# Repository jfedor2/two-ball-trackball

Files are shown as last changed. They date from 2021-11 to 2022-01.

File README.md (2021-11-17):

# DIY two-ball trackball

This repository contains design files and code that can be used to make a fully programmable two-ball, three-button USB trackball that looks like this:

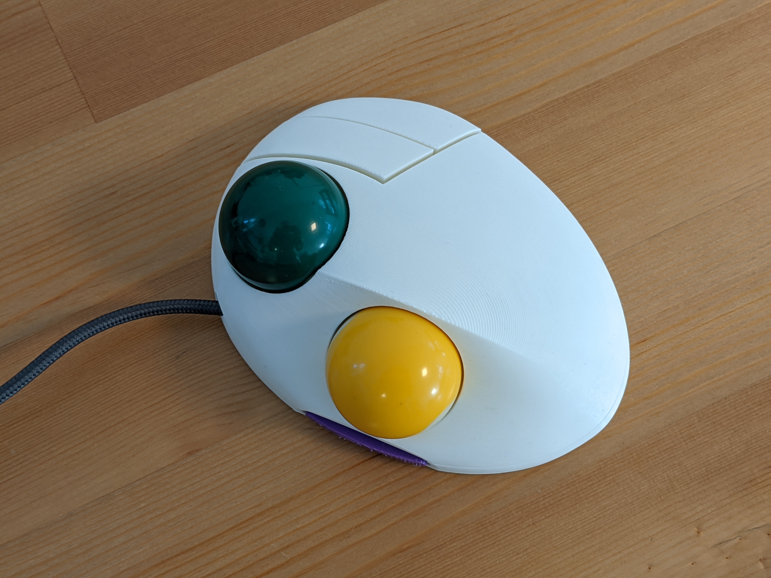
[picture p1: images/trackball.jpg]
Trackball photo


It uses the following components:

* two 38mm billiard balls
* two PMW3360 optical sensors
* [main PCB](https://github.com/jfedor2/rp2040-pmw3360)
* [second sensor PCB](https://github.com/jfedor2/pmw3360-breakout)
* [button switch mount PCBs](https://github.com/jfedor2/mouse-switch-mount-pcb)
* [3D printed case](3d-models)
* Omron D2FC switches (or any switches with the same footprint)
* 2.5mm zirconium oxide (or silicon nitride) bearing balls
* M3x4 screws for mounting the main PCB
* M2x4 screws for mounting the buttons and the secondary PCBs
* 3x10mm wood screws for assembling the case
* USB cable (cut off the device end and solder the wires directly to the PCB)

The main PCB uses the RP2040 chip from Raspberry Pi. The firmware supports remapping of ball and button functions using a configuration tool without the need to recompile the source code. All the configuration is stored on device, so the configuration tool is only needed to change the settings, not during normal use.

Each ball can be configured to control the cursor or to scroll, with independent CPI setting. High resolution scroll is supported (at least on Windows).

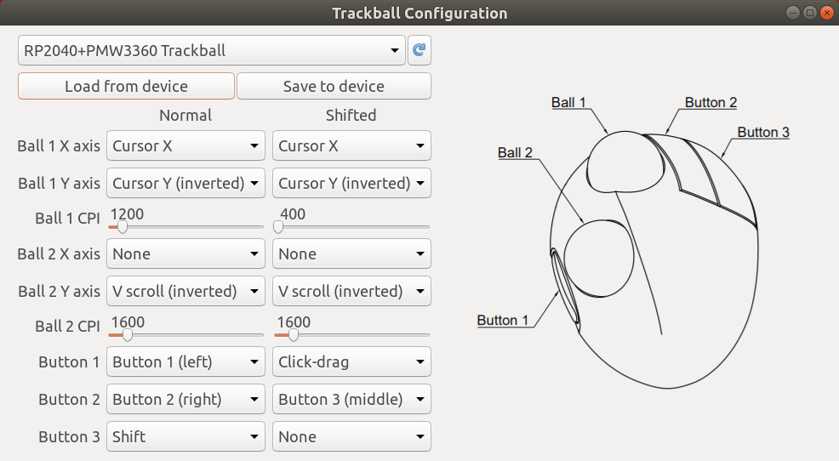
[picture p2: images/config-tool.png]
Configuration tool UI screenshot


So far I only tested the configuration tool on Linux, but it should in theory run on Windows and Mac as well. I will try to provide ready-to-use packages in the future.

The provided [UF2 file](firmware/trackball.uf2) can be used to flash the firmware onto the device. When first connected, a "RPI-RP2" drive will show up and you flash the chip by copying the UF2 file to that drive. If you want to flash it again, hold the BOOT button and press the RESET button on the board.

I printed the case parts with 0.2mm layer height and no supports, though you might want to enable supports for the top part if you're having trouble printing it without them.

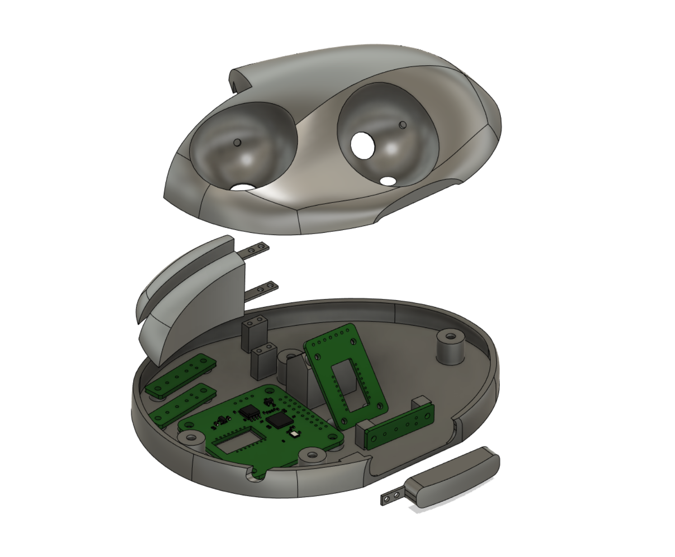
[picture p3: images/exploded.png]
Exploded view


The pin numbers are defined at the top of [trackball.cc](firmware/src/trackball.cc).

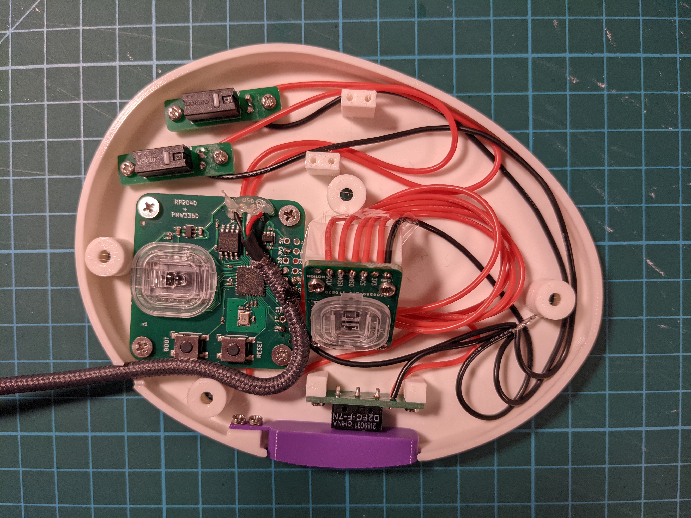
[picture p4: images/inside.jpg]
Insides of the case


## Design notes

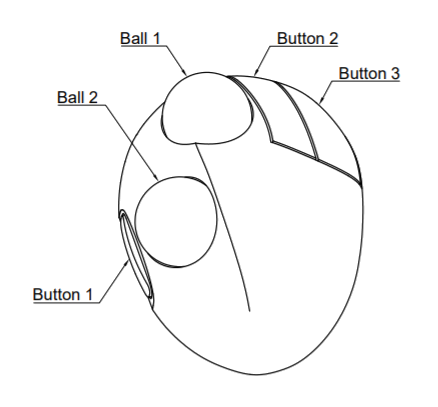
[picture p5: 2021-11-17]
config-tool/trackball.png

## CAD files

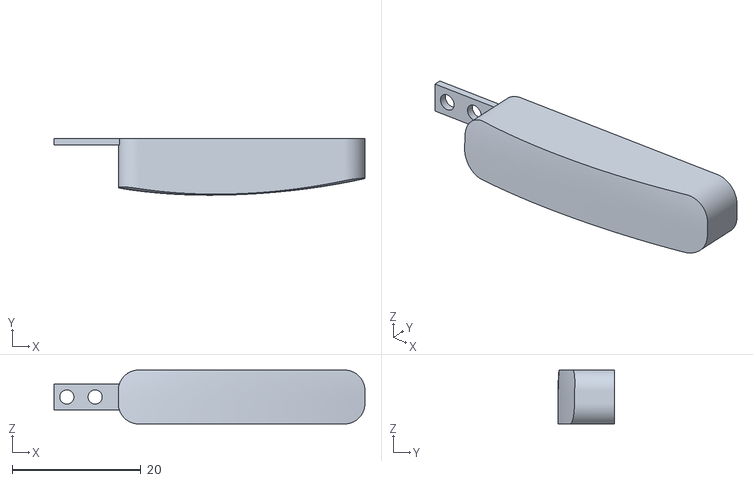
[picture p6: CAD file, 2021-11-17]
3d-models/Trackball12-Button3.stl
48.4 x 8.80 x 8.40

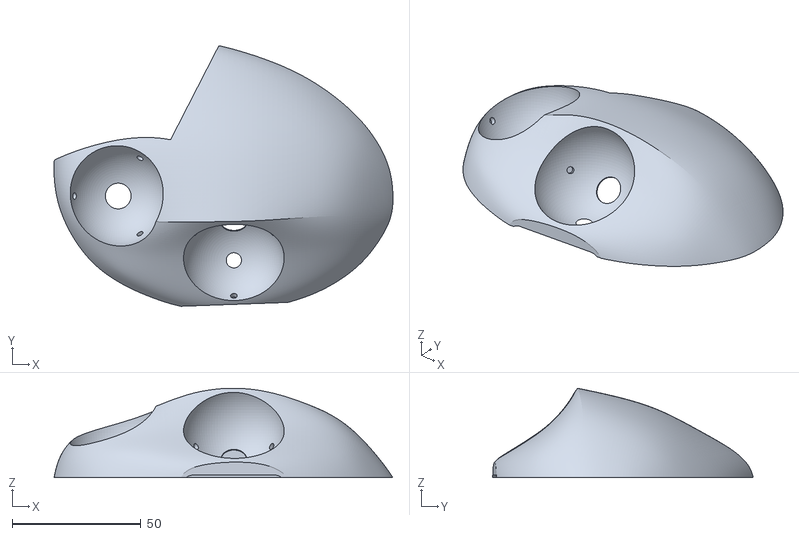
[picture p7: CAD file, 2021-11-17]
3d-models/Trackball12-Case-top.stl
131.9 x 101.4 x 34.8

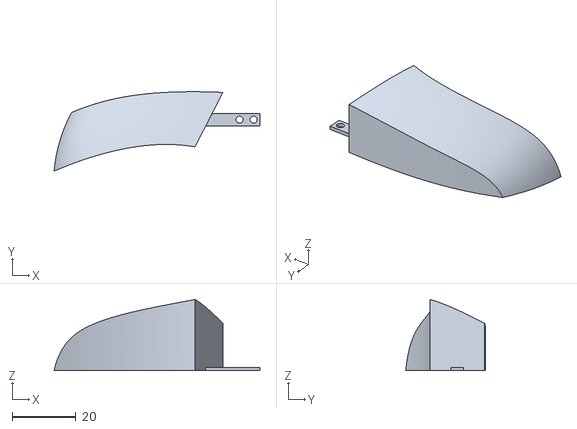
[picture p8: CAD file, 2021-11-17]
3d-models/Trackball12-Button1.stl
64.5 x 24.9 x 22.3

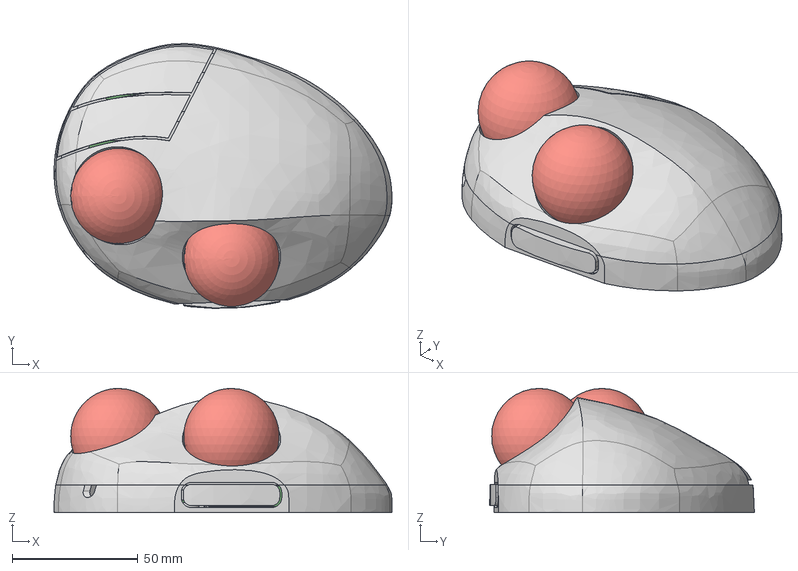
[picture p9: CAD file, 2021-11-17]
3d-models/Trackball12.step
134.5 x 105.4 x 49.4 mm

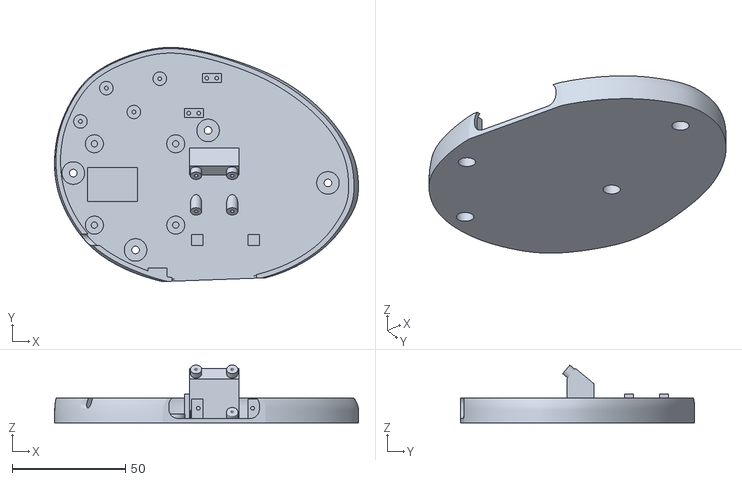
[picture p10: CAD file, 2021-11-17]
3d-models/Trackball12-Case-bottom.stl
134.5 x 103.6 x 25.6

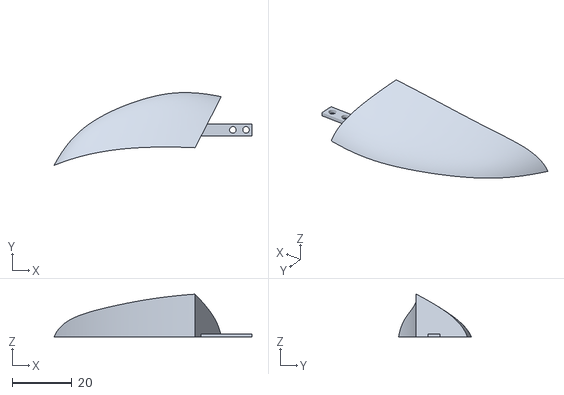
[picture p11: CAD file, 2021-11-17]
3d-models/Trackball12-Button2.stl
66.3 x 24.4 x 14.3

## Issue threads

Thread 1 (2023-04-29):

map the unused rp2040 pcb pins to buttons.

itsnoteasy, 2023-04-29:
I have built this project in a different case. however, there's not many buttons no back/ forward and you have to choose between middle click and layer shift. I'd appreciate it if you could map at least one extra button to the gpio, they're unused anyway. 2 to 3 buttons would be great. I like the layer shift because it prevents back/forward from being hit by accident.

I have tried to compile the code, but couldn't get the build environment setup. sorry for hassling you.

Closed 2023-04-30.

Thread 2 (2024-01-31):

SENSOR0 / BALL 1 stuck in perpetual diagonal movement

flacks, 2024-01-31:
SENSOR0 / BALL 1 seems to be stuck in perpetual diagonal movement. If I set the X axis to Cursor X and Y axis to Cursor Y (inverted), cursor perpetually moves down and to the right, diagonally. Accordingly, if I set Y axis to Cursor Y (not inverted), cursor perpetually moves up and to the right, diagonally. Any idea on how to debug this? Could it be a faulty PMW3360 sensor?

flacks, 2024-01-31:
I tried using the provided trackball.uf2 as well as building the firmware with the last Pico SDK, to the same result.

flacks, 2024-02-12:
Resolved - bad sensor. Thank you kindly, @jfedor2, for your help offline!

Closed 2024-02-12.

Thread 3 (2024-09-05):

Detailed wiring guide

tangbonze, 2024-09-05:
Your design is really fascinating. I want to make one myself.
In terms of wiring, I'm a little unclear how the second sensor and the switch connect to the pins of the main pcb.
Can you provide a clear wiring diagram?
Thanks a lot.

tangbonze, 2024-09-06:
Thanks a lot!

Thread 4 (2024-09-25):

Source for PWM3360 sensor and lense

PumaFPV, 2024-09-25:
Hey, where do you source your PWM3360 sensor and lenses please?
Thanks

jfedor2, 2024-09-25:
AliExpress.

PumaFPV, 2024-10-16:
Thanks for the answer. I hoped there was a better source :/

Closed 2024-10-16.

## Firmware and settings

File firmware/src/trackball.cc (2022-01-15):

/* 
 * The MIT License (MIT)
 *
 * Copyright (c) 2021 Jacek Fedorynski
 * Copyright (c) 2019 Ha Thach (tinyusb.org)
 *
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
 */

#include <stdio.h>
#include <stdlib.h>
#include <string.h>

#include <bsp/board.h>
#include <tusb.h>

#include <pico/bootrom.h>
#include <pico/stdlib.h>

#include <hardware/flash.h>
#include <hardware/gpio.h>

#include "crc.h"
#include "pmw3360.h"

// These IDs are bogus. If you want to distribute any hardware using this,
// you will have to get real ones.
#define USB_VID 0xCAFE
#define USB_PID 0xBACA

#define CONFIG_VERSION 1
#define CONFIG_SIZE 24

#define NBALLS 2
#define NBUTTONS 3

#define PRESUMED_FLASH_SIZE 2097152
#define CONFIG_OFFSET_IN_FLASH (PRESUMED_FLASH_SIZE - FLASH_SECTOR_SIZE)
#define FLASH_CONFIG_IN_MEMORY (((uint8_t*) XIP_BASE) + CONFIG_OFFSET_IN_FLASH)

uint button_pins[NBUTTONS] = { 16, 24, 26 };

#define SENSOR0_SPI spi0
#define SENSOR0_MISO 4
#define SENSOR0_MOSI 3
#define SENSOR0_SCK 2
#define SENSOR0_NCS 9
#define SENSOR1_SPI spi0
#define SENSOR1_MISO 20
#define SENSOR1_MOSI 23
#define SENSOR1_SCK 18
#define SENSOR1_NCS 25

PMW3360 sensors[NBALLS] = {
    PMW3360(SENSOR0_SPI, SENSOR0_MISO, SENSOR0_MOSI, SENSOR0_SCK, SENSOR0_NCS),
    PMW3360(SENSOR1_SPI, SENSOR1_MISO, SENSOR1_MOSI, SENSOR1_SCK, SENSOR1_NCS),
};

tusb_desc_device_t const desc_device = {
    .bLength = sizeof(tusb_desc_device_t),
    .bDescriptorType = TUSB_DESC_DEVICE,
    .bcdUSB = 0x0200,
    .bDeviceClass = 0x00,
    .bDeviceSubClass = 0x00,
    .bDeviceProtocol = 0x00,
    .bMaxPacketSize0 = CFG_TUD_ENDPOINT0_SIZE,

    .idVendor = USB_VID,
    .idProduct = USB_PID,
    .bcdDevice = 0x0100,

    .iManufacturer = 0x01,
    .iProduct = 0x02,
    .iSerialNumber = 0x00,

    .bNumConfigurations = 0x01,
};

uint8_t const desc_hid_report[] = {
    0x05, 0x01,         // Usage Page (Generic Desktop Ctrls)
    0x09, 0x02,         // Usage (Mouse)
    0xA1, 0x01,         // Collection (Application)
    0x05, 0x01,         //   Usage Page (Generic Desktop Ctrls)
    0x09, 0x02,         //   Usage (Mouse)
    0xA1, 0x02,         //   Collection (Logical)
    0x85, 0x01,         //     Report ID (1)
    0x09, 0x01,         //     Usage (Pointer)
    0xA1, 0x00,         //     Collection (Physical)
    0x05, 0x09,         //       Usage Page (Button)
    0x19, 0x01,         //       Usage Minimum (0x01)
    0x29, 0x08,         //       Usage Maximum (0x08)
    0x95, 0x08,         //       Report Count (8)
    0x75, 0x01,         //       Report Size (1)
    0x25, 0x01,         //       Logical Maximum (1)
    0x81, 0x02,         //       Input (Data,Var,Abs,No Wrap,Linear,Preferred State,No Null Position)
    0x05, 0x01,         //       Usage Page (Generic Desktop Ctrls)
    0x09, 0x30,         //       Usage (X)
    0x09, 0x31,         //       Usage (Y)
    0x95, 0x02,         //       Report Count (2)
    0x75, 0x10,         //       Report Size (16)
    0x16, 0x00, 0x80,   //       Logical Minimum (-32768)
    0x26, 0xFF, 0x7F,   //       Logical Maximum (32767)
    0x81, 0x06,         //       Input (Data,Var,Rel,No Wrap,Linear,Preferred State,No Null Position)
    0xA1, 0x02,         //       Collection (Logical)
    0x85, 0x02,         //         Report ID (2)
    0x09, 0x48,         //         Usage (Resolution Multiplier)
    0x95, 0x01,         //         Report Count (1)
    0x75, 0x02,         //         Report Size (2)
    0x15, 0x00,         //         Logical Minimum (0)
    0x25, 0x01,         //         Logical Maximum (1)
    0x35, 0x01,         //         Physical Minimum (1)
    0x45, 0x78,         //         Physical Maximum (120)
    0xB1, 0x02,         //         Feature (Data,Var,Abs,No Wrap,Linear,Preferred State,No Null Position,Non-volatile)
    0x85, 0x01,         //         Report ID (1)
    0x09, 0x38,         //         Usage (Wheel)
    0x35, 0x00,         //         Physical Minimum (0)
    0x45, 0x00,         //         Physical Maximum (0)
    0x16, 0x00, 0x80,   //         Logical Minimum (-32768)
    0x26, 0xFF, 0x7F,   //         Logical Maximum (32767)
    0x75, 0x10,         //         Report Size (16)
    0x81, 0x06,         //         Input (Data,Var,Rel,No Wrap,Linear,Preferred State,No Null Position)
    0xC0,               //       End Collection
    0xA1, 0x02,         //       Collection (Logical)
    0x85, 0x02,         //         Report ID (2)
    0x09, 0x48,         //         Usage (Resolution Multiplier)
    0x75, 0x02,         //         Report Size (2)
    0x15, 0x00,         //         Logical Minimum (0)
    0x25, 0x01,         //         Logical Maximum (1)
    0x35, 0x01,         //         Physical Minimum (1)
    0x45, 0x78,         //         Physical Maximum (120)
    0xB1, 0x02,         //         Feature (Data,Var,Abs,No Wrap,Linear,Preferred State,No Null Position,Non-volatile)
    0x35, 0x00,         //         Physical Minimum (0)
    0x45, 0x00,         //         Physical Maximum (0)
    0x75, 0x04,         //         Report Size (4)
    0xB1, 0x03,         //         Feature (Const,Var,Abs,No Wrap,Linear,Preferred State,No Null Position,Non-volatile)
    0x85, 0x01,         //         Report ID (1)
    0x05, 0x0C,         //         Usage Page (Consumer)
    0x16, 0x00, 0x80,   //         Logical Minimum (-32768)
    0x26, 0xFF, 0x7F,   //         Logical Maximum (32767)
    0x75, 0x10,         //         Report Size (16)
    0x0A, 0x38, 0x02,   //         Usage (AC Pan)
    0x81, 0x06,         //         Input (Data,Var,Rel,No Wrap,Linear,Preferred State,No Null Position)
    0xC0,               //       End Collection
    0xC0,               //     End Collection
    0xC0,               //   End Collection
    0x06, 0x00, 0xFF,   //   Usage Page (Vendor Defined 0xFF00)
    0x09, 0x20,         //   Usage (0x20)
    0x85, 0x03,         //   Report ID (3)
    0x75, 0x08,         //   Report Size (8)
    0x95, CONFIG_SIZE,  //   Report Count (CONFIG_SIZE)
    0xB1, 0x02,         //   Feature (Data,Var,Abs,No Wrap,Linear,Preferred State,No Null Position,Non-volatile)
    0xC0,               // End Collection
};

#define CONFIG_TOTAL_LEN (TUD_CONFIG_DESC_LEN + TUD_HID_DESC_LEN)
#define EPNUM_HID 0x81

uint8_t const desc_configuration[] = {
    // Config number, interface count, string index, total length, attribute, power in mA
    TUD_CONFIG_DESCRIPTOR(1, 1, 0, CONFIG_TOTAL_LEN, 0, 100),

    // Interface number, string index, protocol, report descriptor len, EP In address, size & polling interval
    TUD_HID_DESCRIPTOR(0, 0, HID_ITF_PROTOCOL_NONE, sizeof(desc_hid_report), EPNUM_HID, CFG_TUD_HID_EP_BUFSIZE, 1)
};

char const* string_desc_arr[] = {
    (const char[]){ 0x09, 0x04 },  // 0: is supported language is English (0x0409)
    "RP2040+PMW3360",              // 1: Manufacturer
    "Trackball",                   // 2: Product
};

struct __attribute__((packed)) hid_report_t {
    uint8_t buttons;
    int16_t dx;
    int16_t dy;
    int16_t vwheel;
    int16_t hwheel;
};

hid_report_t report;

enum class ButtonFunction : int8_t {
    NO_FUNCTION = 0,
    BUTTON1 = 1,
    BUTTON2 = 2,
    BUTTON3 = 3,
    BUTTON4 = 4,
    BUTTON5 = 5,
    BUTTON6 = 6,
    BUTTON7 = 7,
    BUTTON8 = 8,
    CLICK_DRAG = 9,
    SHIFT = 10,
};

enum class BallFunction : int8_t {
    NO_FUNCTION = 0,
    CURSOR_X = 1,
    CURSOR_Y = 2,
    VERTICAL_SCROLL = 3,
    HORIZONTAL_SCROLL = 4,
    CURSOR_X_INVERTED = -1,
    CURSOR_Y_INVERTED = -2,
    VERTICAL_SCROLL_INVERTED = -3,
    HORIZONTAL_SCROLL_INVERTED = -4,
};

enum class ConfigCommand : int8_t {
    NO_COMMAND = 0,
    RESET_INTO_BOOTSEL = 1,
};

struct __attribute__((packed)) config_t {
    uint8_t version;
    ConfigCommand command;
    BallFunction ball_function[NBALLS][2];
    BallFunction ball_shifted_function[NBALLS][2];
    uint8_t ball_cpi[NBALLS];
    uint8_t ball_shifted_cpi[NBALLS];
    ButtonFunction button_function[NBUTTONS];
    ButtonFunction button_shifted_function[NBUTTONS];
    uint32_t crc32;
};

config_t config = {
    .version = CONFIG_VERSION,
    .command = ConfigCommand::NO_COMMAND,
    .ball_function = {
        { BallFunction::CURSOR_X, BallFunction::CURSOR_Y_INVERTED },
        { BallFunction::VERTICAL_SCROLL, BallFunction::NO_FUNCTION },
    },
    .ball_shifted_function = {
        { BallFunction::CURSOR_X, BallFunction::CURSOR_Y_INVERTED },
        { BallFunction::VERTICAL_SCROLL, BallFunction::NO_FUNCTION },
    },
    .ball_cpi = {
        600 / 100,
        800 / 100,
    },
    .ball_shifted_cpi = {
        600 / 100,
        800 / 100,
    },
    .button_function = {
        ButtonFunction::BUTTON1,
        ButtonFunction::BUTTON3,
        ButtonFunction::BUTTON2,
    },
    .button_shifted_function = {
        ButtonFunction::BUTTON1,
        ButtonFunction::BUTTON3,
        ButtonFunction::BUTTON2,
    },
    .crc32 = 0,
};

uint8_t resolution_multiplier = 0;

int accumulated_scroll[NBALLS][2] = { 0 };
uint64_t last_scroll_timestamp[NBALLS][2] = { 0 };
uint32_t prev_pin_state = 0xffffffff;
bool click_drag = false;
uint8_t current_cpi[NBALLS] = { 0 };

int16_t handle_scroll(int ball, int axis, BallFunction ball_function, int16_t movement, uint8_t multiplier_mask) {
    int16_t ret = 0;
    if (resolution_multiplier & multiplier_mask) {
        ret = movement;
    } else {
        if (movement != 0) {
            last_scroll_timestamp[ball][axis] = time_us_64();
            accumulated_scroll[ball][axis] += movement;
            int ticks = accumulated_scroll[ball][axis] / 120;
            accumulated_scroll[ball][axis] -= ticks * 120;
            ret = ticks;
        } else {
            if ((accumulated_scroll[ball][axis] != 0) &&
                (time_us_64() - last_scroll_timestamp[ball][axis] > 1000000)) {
                accumulated_scroll[ball][axis] = 0;
            }
        }
    }
    return ret;
}

void hid_task() {
    if (!tud_hid_ready()) {
        return;
    }

    memset(&report, 0, sizeof(report));

    uint32_t pin_state = gpio_get_all();

    bool shifted = false;

    // first pass to determine if we're in shifted state
    for (int i = 0; i < NBUTTONS; i++) {
        if (config.button_function[i] == ButtonFunction::SHIFT &&
            !(pin_state & (1 << button_pins[i]))) {
            shifted = true;
        }
    }

    // set CPI if not already correct
    for (int i = 0; i < NBALLS; i++) {
        uint8_t wanted_cpi = shifted ? config.ball_shifted_cpi[i] : config.ball_cpi[i];
        if (current_cpi[i] != wanted_cpi && wanted_cpi >= 1 && wanted_cpi <= 120) {
            sensors[i].set_cpi(wanted_cpi * 100);
            current_cpi[i] = wanted_cpi;
        }
    }

    for (int i = 0; i < NBUTTONS; i++) {
        ButtonFunction button_function =
            shifted ? config.button_shifted_function[i] : config.button_function[i];
        if (config.button_function[i] == ButtonFunction::SHIFT) {
            button_function = ButtonFunction::NO_FUNCTION;
        }
        switch (button_function) {
            case ButtonFunction::NO_FUNCTION:
            case ButtonFunction::SHIFT:
                break;
            case ButtonFunction::BUTTON1:
            case ButtonFunction::BUTTON2:
            case ButtonFunction::BUTTON3:
            case ButtonFunction::BUTTON4:
            case ButtonFunction::BUTTON5:
            case ButtonFunction::BUTTON6:
            case ButtonFunction::BUTTON7:
            case ButtonFunction::BUTTON8: {
                int button = static_cast<int>(button_function) - 1;
                if (!(pin_state & (1 << button_pins[i]))) {
                    report.buttons |= 1 << button;
                }
                break;
            }
            case ButtonFunction::CLICK_DRAG:
                if ((prev_pin_state & (1 << button_pins[i])) &&
                    !(pin_state & (1 << button_pins[i]))) {
                    click_drag = !click_drag;
                }
                break;
        }
    }

    if (click_drag) {
        report.buttons |= 1 << 0;
    }

    prev_pin_state = pin_state;

    for (int ball = 0; ball < NBALLS; ball++) {
        sensors[ball].update();
        for (int axis = 0; axis < 2; axis++) {
            int16_t movement = sensors[ball].movement[axis];
            BallFunction ball_function =
                shifted ? config.ball_shifted_function[ball][axis] : config.ball_function[ball][axis];
            if (static_cast<int>(ball_function) < 0) {
                movement *= -1;
            }
            switch (ball_function) {
                case BallFunction::NO_FUNCTION:
                    break;
                case BallFunction::CURSOR_X:
                case BallFunction::CURSOR_X_INVERTED:
                    report.dx += movement;
                    break;
                case BallFunction::CURSOR_Y:
                case BallFunction::CURSOR_Y_INVERTED:
                    report.dy += movement;
                    break;
                case BallFunction::VERTICAL_SCROLL:
                case BallFunction::VERTICAL_SCROLL_INVERTED:
                    report.vwheel += handle_scroll(ball, axis, ball_function, movement, 1 << 0);
                    break;
                case BallFunction::HORIZONTAL_SCROLL:
                case BallFunction::HORIZONTAL_SCROLL_INVERTED:
                    report.hwheel += handle_scroll(ball, axis, ball_function, movement, 1 << 2);
                    break;
            }
        }
    }

    // uncomment to have pressing all three buttons reset into BOOTSEL
    // (convenient during development)
    // if (!(pin_state & (1 << button_pins[0]) ||
    //       pin_state & (1 << button_pins[1]) ||
    //       pin_state & (1 << button_pins[2]))) {
    //     reset_usb_boot(0, 0);
    // }

    tud_hid_report(1, &report, sizeof(report));
}

void pin_init(uint pin) {
    gpio_init(pin);
    gpio_set_dir(pin, GPIO_IN);
    gpio_pull_up(pin);
}

void pins_init() {
    for (int i = 0; i < NBUTTONS; i++) {
        pin_init(button_pins[i]);
    }
}

void sensors_init() {
    for (int i = 0; i < NBALLS; i++) {
        sensors[i].init();
    }
}

void run_config_command() {
    // we probably shouldn't do this for config read from flash
    // or let's just not write any non-null command to flash
    if (config.command == ConfigCommand::RESET_INTO_BOOTSEL) {
        reset_usb_boot(0, 0);
    }
}

bool checksum_ok(const uint8_t* buffer) {
    return crc32(buffer, CONFIG_SIZE - 4) == ((config_t*) buffer)->crc32;
}

bool version_ok(const uint8_t* buffer) {
    return ((config_t*) buffer)->version == CONFIG_VERSION;
}

void load_config() {
    if (checksum_ok(FLASH_CONFIG_IN_MEMORY) && version_ok(FLASH_CONFIG_IN_MEMORY)) {
        memcpy(&config, FLASH_CONFIG_IN_MEMORY, CONFIG_SIZE);
    }
}

void persist_config() {
    uint8_t buffer[FLASH_PAGE_SIZE];
    memset(buffer, 0, sizeof(buffer));
    memcpy(buffer, &config, CONFIG_SIZE);
    uint32_t ints = save_and_disable_interrupts();
    flash_range_erase(CONFIG_OFFSET_IN_FLASH, FLASH_SECTOR_SIZE);
    flash_range_program(CONFIG_OFFSET_IN_FLASH, buffer, FLASH_PAGE_SIZE);
    restore_interrupts(ints);
}

int main() {
    stdio_init_all();
    board_init();
    load_config();
    pins_init();
    sensors_init();
    tusb_init();

    while (true) {
        tud_task();  // tinyusb device task
        hid_task();
    }

    return 0;
}

// Invoked when device is mounted
void tud_mount_cb() {
    // reset hi-res scroll for when we reboot from Windows into Linux
    resolution_multiplier = 0;
}

// Invoked when received GET DEVICE DESCRIPTOR
// Application return pointer to descriptor
uint8_t const* tud_descriptor_device_cb() {
    return (uint8_t const*) &desc_device;
}

// Invoked when received GET HID REPORT DESCRIPTOR
// Application return pointer to descriptor
// Descriptor contents must exist long enough for transfer to complete
uint8_t const* tud_hid_descriptor_report_cb(uint8_t itf) {
    return desc_hid_report;
}

// Invoked when received GET_REPORT control request
// Application must fill buffer report's content and return its length.
// Return zero will cause the stack to STALL request
uint16_t tud_hid_get_report_cb(uint8_t itf, uint8_t report_id, hid_report_type_t report_type, uint8_t* buffer, uint16_t reqlen) {
    if (report_id == 2 && reqlen >= 1) {
        memcpy(buffer, &resolution_multiplier, 1);
        return 1;
    }
    if (report_id == 3 && reqlen >= CONFIG_SIZE) {
        config.crc32 = crc32((uint8_t*) &config, CONFIG_SIZE - 4);
        memcpy(buffer, &config, CONFIG_SIZE);
        return CONFIG_SIZE;
    }

    return 0;
}

// Invoked when received SET_REPORT control request or
// received data on OUT endpoint ( Report ID = 0, Type = 0 )
void tud_hid_set_report_cb(uint8_t itf, uint8_t report_id, hid_report_type_t report_type, uint8_t const* buffer, uint16_t bufsize) {
    if (report_id == 2 && bufsize >= 1) {
        memcpy(&resolution_multiplier, buffer, 1);
    }
    if (report_id == 3 && bufsize >= CONFIG_SIZE) {
        if (checksum_ok(buffer) && version_ok(buffer)) {
            memcpy(&config, buffer, CONFIG_SIZE);
            run_config_command();
            persist_config();
        }
    }
}

// Invoked when received GET CONFIGURATION DESCRIPTOR
// Application return pointer to descriptor
// Descriptor contents must exist long enough for transfer to complete
uint8_t const* tud_descriptor_configuration_cb(uint8_t index) {
    return desc_configuration;
}

static uint16_t _desc_str[32];

// Invoked when received GET STRING DESCRIPTOR request
// Application return pointer to descriptor, whose contents must exist long enough for transfer to complete
uint16_t const* tud_descriptor_string_cb(uint8_t index, uint16_t langid) {
    uint8_t chr_count;

    if (index == 0) {
        memcpy(&_desc_str[1], string_desc_arr[0], 2);
        chr_count = 1;
    } else {
        // Note: the 0xEE index string is a Microsoft OS 1.0 Descriptors.
        // https://docs.microsoft.com/en-us/windows-hardware/drivers/usbcon/microsoft-defined-usb-descriptors

        if (!(index < sizeof(string_desc_arr) / sizeof(string_desc_arr[0])))
            return NULL;

        const char* str = string_desc_arr[index];

        // Cap at max char
        chr_count = strlen(str);
        if (chr_count > 31)
            chr_count = 31;

        // Convert ASCII string into UTF-16
        for (uint8_t i = 0; i < chr_count; i++) {
            _desc_str[1 + i] = str[i];
        }
    }

    // first byte is length (including header), second byte is string type
    _desc_str[0] = (TUSB_DESC_STRING << 8) | (2 * chr_count + 2);

    return _desc_str;
}

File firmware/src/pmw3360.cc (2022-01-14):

// derived from https://github.com/mrjohnk/PMW3360DM-T2QU

#include <hardware/gpio.h>

#include "pmw3360.h"

#include "registers.h"
#include "srom.h"

void PMW3360::init() {
    set_pins_function();

    gpio_init(ncs_pin);
    gpio_set_dir(ncs_pin, GPIO_OUT);
    gpio_put(ncs_pin, 1);

    spi_init(spi, 500000);
    spi_set_format(spi, 8, SPI_CPOL_1, SPI_CPHA_1, SPI_MSB_FIRST);

    perform_startup();

    unset_pins_function();
}

void PMW3360::set_cpi(unsigned int cpi) {
    set_pins_function();

    int cpival = (cpi / 100) - 1;
    cs_select();
    write_register(Config1, cpival);
    cs_deselect();

    unset_pins_function();
}

void PMW3360::update() {
    set_pins_function();

    // write 0x01 to Motion register and read from it to freeze the motion values and make them available
    write_register(Motion, 0x01);
    uint8_t motion = read_register(Motion);

    is_on_surface = !(motion & (1 << 3));

    movement[0] = read_register(Delta_X_L);
    movement[0] |= ((int16_t) read_register(Delta_X_H)) << 8;
    movement[1] = read_register(Delta_Y_L);
    movement[1] |= ((int16_t) read_register(Delta_Y_H)) << 8;

    unset_pins_function();
}

void PMW3360::cs_select() {
    asm volatile("nop \n nop \n nop");
    gpio_put(ncs_pin, 0);  // Active low
    asm volatile("nop \n nop \n nop");
}

void PMW3360::cs_deselect() {
    asm volatile("nop \n nop \n nop");
    gpio_put(ncs_pin, 1);
    asm volatile("nop \n nop \n nop");
}

uint8_t PMW3360::read_register(uint8_t reg_addr) {
    cs_select();

    // send adress of the register, with MSBit = 0 to indicate it's a read
    uint8_t x = reg_addr & 0x7f;
    spi_write_blocking(spi, &x, 1);
    sleep_us(100);  // tSRAD
    // read data
    uint8_t data;
    spi_read_blocking(spi, 0, &data, 1);

    sleep_us(1);  // tSCLK-NCS for read operation is 120ns
    cs_deselect();
    sleep_us(19);  // tSRW/tSRR (=20us) minus tSCLK-NCS

    return data;
}

void PMW3360::write_register(uint8_t reg_addr, uint8_t data) {
    cs_select();

    // send adress of the register, with MSBit = 1 to indicate it's a write
    uint8_t x = reg_addr | 0x80;
    spi_write_blocking(spi, &x, 1);
    // send data
    spi_write_blocking(spi, &data, 1);

    sleep_us(20);  // tSCLK-NCS for write operation
    cs_deselect();
    sleep_us(100);  // tSWW/tSWR (=120us) minus tSCLK-NCS. Could be shortened, but is looks like a safe lower bound
}

// We do this because we have the two sensors connected to two different sets of spi0 pins.
// It wouldn't be necessary if one sensor was connected to spi0 and the other to spi1.
// (Or even if we had both connected to the same spi0 pins, I think.)
void PMW3360::set_pins_function() {
    gpio_set_function(miso_pin, GPIO_FUNC_SPI);
    gpio_set_function(mosi_pin, GPIO_FUNC_SPI);
    gpio_set_function(sck_pin, GPIO_FUNC_SPI);
}

void PMW3360::unset_pins_function() {
    gpio_set_function(miso_pin, GPIO_FUNC_NULL);
    gpio_set_function(mosi_pin, GPIO_FUNC_NULL);
    gpio_set_function(sck_pin, GPIO_FUNC_NULL);
}

void PMW3360::perform_startup() {
    cs_deselect();                         // ensure that the serial port is reset
    cs_select();                           // ensure that the serial port is reset
    cs_deselect();                         // ensure that the serial port is reset
    write_register(Power_Up_Reset, 0x5a);  // force reset
    sleep_ms(50);                          // wait for it to reboot
    // read registers 0x02 to 0x06 (and discard the data)
    read_register(Motion);
    read_register(Delta_X_L);
    read_register(Delta_X_H);
    read_register(Delta_Y_L);
    read_register(Delta_Y_H);
    // upload the firmware
    upload_firmware();
    sleep_ms(10);
}

void PMW3360::upload_firmware() {
    // send the firmware to the chip, cf p.18 of the datasheet

    // Write 0 to Rest_En bit of Config2 register to disable Rest mode.
    write_register(Config2, 0x20);

    // write 0x1d in SROM_enable reg for initializing
    write_register(SROM_Enable, 0x1d);

    // wait for more than one frame period
    sleep_ms(10);  // assume that the frame rate is as low as 100fps... even if it should never be that low

    // write 0x18 to SROM_enable to start SROM download
    write_register(SROM_Enable, 0x18);

    // write the SROM file (=firmware data)
    cs_select();
    uint8_t data = SROM_Load_Burst | 0x80;  // write burst destination adress
    spi_write_blocking(spi, &data, 1);
    sleep_us(15);

    // send all bytes of the firmware
    for (int i = 0; i < firmware_length; i++) {
        spi_write_blocking(spi, &(firmware_data[i]), 1);
        sleep_us(15);
    }

    // Read the SROM_ID register to verify the ID before any other register reads or writes.
    read_register(SROM_ID);

    // Write 0x00 to Config2 register for wired mouse or 0x20 for wireless mouse design.
    write_register(Config2, 0x00);

    // set initial CPI resolution
    write_register(Config1, 0x15);

    cs_deselect();
}

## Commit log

2022-01-14 Fix is_on_surface
    It's not actually used for anything, but is_on_surface flag was flipped.
    [pmw3360.cc]
2022-01-14 Avoid taking address of packed struct members
    ... which may result in unaligned pointers.
    [trackball.cc]
2022-01-15 Don't fetch sensor data if !tud_hid_ready()
    Moves the tud_hid_ready() check to the beginning of the hid_task()
    function, so that we don't drop sensor readings if USB is not ready.
    With this change, the sensor keeps accumulating the deltas until we're
    ready for them.
    Also changes the default CPI to half of the previous values, which
    should hopefully match previous behavior now that we're not dropping
    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
